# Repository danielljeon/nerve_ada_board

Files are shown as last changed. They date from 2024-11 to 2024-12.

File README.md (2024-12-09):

# nerve_ada_board



Nerve dev board using off-the-shelf modules.

> **Note: This design is now no longer under active development. The final
changes to the main branch are published as release tagged `v0.1.0-beta`,
see the release notes: [1.1 v0.1.0-beta](#11-v010-beta).**

> 💡**Hint:** To clone this repository use:
> ```shell
> git clone --recursive
> ```

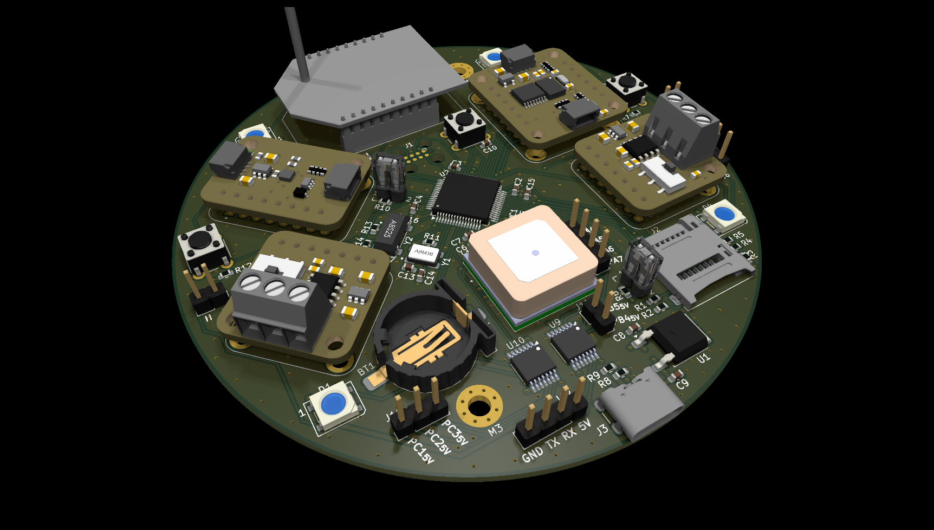
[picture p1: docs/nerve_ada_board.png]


---

<details markdown="1">
  <summary>Table of Contents</summary>

<!-- TOC -->
* [nerve_ada_board](#nerve_ada_board)
  * [1 Release Notes](#1-release-notes)
    * [1.1 v0.1.0-beta](#11-v010-beta)
      * [1.1.1 LSE Crystal](#111-lse-crystal)
      * [1.1.2 External Clock Crystal Tuning](#112-external-clock-crystal-tuning)
      * [1.1.3 GPS](#113-gps)
  * [2 Overview](#2-overview)
    * [2.1 Function Connectors](#21-function-connectors)
    * [2.2 Switches & Jumpers](#22-switches--jumpers)
    * [2.3 Plug-in Modules](#23-plug-in-modules)
    * [2.4 Breakout Connectors](#24-breakout-connectors)
  * [3 Development](#3-development)
    * [3.1 Worflow](#31-worflow)
    * [3.2 Submodules](#32-submodules)
  * [4 Production History](#4-production-history)
    * [4.1 v0.1.0-alpha-7b18788](#41-v010-alpha-7b18788)
<!-- TOC -->

</details>

---

## 1 Release Notes

### 1.1 v0.1.0-beta

Following the initial validation of components and software on this PCB design,
development has shifted to a more production-oriented
board: [nerve_pcb](https://github.com/danielljeon/nerve_pcb). While the base
components remain similar, many have been modified, with further
changes expected.

During the development of the new design, several hardware and PCB issues were
identified. Although this `README.md` will no longer be updated, the following
sections document the known issues as of the final release.

#### 1.1.1 LSE Crystal

The current LSE crystal on the STM32F446RE is the ABS25-32.768KHZ-6-T.

This is not the intended component; the correct crystal should have been the
`ABS25-32.768KHZ-T`, which has a more appropriate load capacitance specification
of 12.5 pF. The `ABS25-32.768KHZ-6-T` variant, with a 6 pF load capacitance, was
used inadvertently.

#### 1.1.2 External Clock Crystal Tuning

The crystal circuits use calculated capacitors that have not yet been fully
verified or fine-tuned. Specifically, the 32.768 kHz LSE crystal is likely using
incorrect capacitors with a value of 1.5 pF.

#### 1.1.3 GPS

The GPS module (`SAM-M10Q`) had not been verified to be functional as of the
release. However, this is likely due to software limitations rather than issues
with the hardware or PCB design.

---

## 2 Overview

Development board for the STM32
based [nerve](https://github.com/danielljeon/nerve) controller firmware.

### 2.1 Function Connectors

These connectors are fixed by hardware (PCB traces or the connector itself).

| Connector | Ref | Description |
|---|:---:|---|
| Tag-Connect TC2050 | J1  | Programming/debug connector |
| Hinge microSD Card | J2  | Portable storage, see [Molex product video](https://youtu.be/YY2V8z6UK7M?t=95) |
| USB-C 5 V Power | J3  | Power only USB-C, primary 5 V source |
| CR1220 Battery | BT1 | MCU and GPS battery source 3.3 V supply |
| CAN1 (Transceiver U7) | J7  | Pin 1: CAN1 High, Pin 2: CAN1 Low |
| CAN2 (Transceiver U8) | J8  | Pin 1: CAN2 High, Pin 2: CAN2 Low |

### 2.2 Switches & Jumpers

User controllable hardware and/or firmware driven inputs.

| Switch/Jumper | Ref | Description |
|---|:---:|---|
| MCU NRESET Switch | SW1 | Generic 6 mm TH button, push to reset |
| MCU PA0 Switch | SW2 | Generic 6 mm TH button, designed for SYS_WKUP0 |
| MCU PC13 Switch | SW3 | Generic 6 mm TH button, designed for SYS_WKUP1 |
| SDIO Card Detect Jumper | J4  | Close for card inserted (pull-down on close) |
| BOOT0 Jumper | J5  | Open for run flash memory (pull-down on open)  |

### 2.3 Plug-in Modules

Off-the-shelf plug-in boards, primarily from Adafruit.

| Manufacturer Part Number |  Ref | Manufacturer | Hardware Interface | Quantity | Description |
|---|:---:|---|---|---:|---|
| 4816 | U3 | Adafruit Industries LLC | 2.54 mm pitch TH | 1 | BMP390 Module |
| Digi XBee-PRO 900HP | U5 | Digi | 2 mm pitch TH | 1 | Long Range 900 MHz OEM RF Module |
| 4754 | U6 | Adafruit Industries LLC | 2.54 mm pitch TH | 1 | BNO085 Module |
| 5708 | U7, U8 | Adafruit Industries LLC | 2.54 mm pitch TH | 2 | TJA1051T/3 Module |

### 2.4 Breakout Connectors

Simple breakout connectors, driven fully or partially by firmware. See schematic
and firmware docs for details.

| Connector | Ref | Logic | Description |
|---|:---:|:-----:|---|
| WS2812B Extender | J6  |  5 V  | Pin 1: PWM, Pin 2: Ground, use separate supply (preventing over current draw) and common ground |
| SPI Breakout | J9  | 3.3 V | Pin 1: CS, Pin 2: SCK, Pin 3: MISO, Pin 4: MOSI |
| GPIO Breakout | J10 |  5 V  | Pin 1, 2, 3: GPIO 1, 2, 3 |
| PWM Breakout | J11 |  5 V  | Pin 1, 2: PWM 1, 2 |
| UART Camera | J12 |  5 V  | Pin 1: 5 V, Pin 2: UART RX, Pin 3: UART TX, Pin 4: Ground, design for low current camera |

---

## 3 Development

### 3.1 Worflow

Developed using KiCad with KiBot GitHub Actions
workflow, [kibot.yaml](.github/workflows/kibot.yaml).

- KiBot configurations found in [config.kibot.yaml](config.kibot.yaml).

CI/CD objectives:

1. ERC (Electrical Rule Check).
2. DRC (Design Rule Check).
3. PCB docs.
    - PCB layer docs (`.pdf` and `.svg`).
4. PCB manufacturing.
    - Gerber files (`.grb`).
    - Drill file (`.drl` and `.pdf` reference docs).
5. Assembly (fabrication service & hand assembly).
    - Pick-and-place assembly position file (`.pos`).
    - Component distributor ordering BoM (`.csv`).
    - General BoMs (`.xlsx` and `.html`).
    - Component placement guide (`.html`).
6. CAD.
    - (`.step`).

### 3.2 Submodules

This repository includes the submodule `component_library`, located
at: [component_library](https://github.com/danielljeon/component_library).

When cloning the repository, make sure to use the recursive option:

```shell
git clone --recursive
```

To update the submodule to its latest version in a cloned repository, use the
following command:

> Note: This is not recommended for this deprecated repository, as pulling
> updates from the submodule's latest commit may result in incompatibilities.

```shell
git submodule update --remote --merge
```

---

## 4 Production History

### 4.1 v0.1.0-alpha-7b18788

Commit: [7b18788](https://github.com/danielljeon/nerve_ada_board/commit/7b187884c03f280627d8443d2d9cc163f4b6956e).

<details markdown="1">
  <summary>Manufacturing & Assembly Details</summary>

**Manufacturing Information:**

Production date: 2024-10-22.

- Manufacturer: JLCPCB.
- Order: PCB, stencil.
- PCB specs (non-default):
    - PCB quantity: 5.
    - Surface Finish: LeadFree HASL.
    - Impedance control stackup: `JLC041611-7628`.
        - Outer Copper Weight: 1 oz.
        - Inner Copper Weight: 1 oz.
- Stencil specs (non-default):
    - Stencil quantity: 1.
    - Custom size: 100 mm x 100 mm (matching PCB dimensions).

**Assembly Information:**

Assembly date: 2024-11-09 to 2024-11-13.

- Assembled PCB quantity: 2.
- Process:
    - Stencil solder paste print by hand & soldering iron.
        - Solder paste: Chip Quik TS391LT `Bi57.6Sn42Ag0.4`.
    - SMD pick-and-place by hand.
    - Reflow with oven.
        - Roughly correct temperatures to solder paste docs.
        - Approximately doubled soak time due to oven limitations.

1. PCB 1 Notes:
    - Components: All placed except for GPS.
    - Damage to though holes for connector J4 mostly on bottom side.
        - First assembly was unsatisfactory.
        - Attempt to remove solder to reassemble header pins resulted in damage
          from aggressive force with the soldering iron.
        - Final result was functional, but the board damage remains on bottom
          side.
            - Suggested correction: heat soak the board, note also left in board
              evaluation section of this writeup.
        - Continuity tests showed no issues after completion.
    - Bridged pins on the U2 (STM32F446RE).
        - Likely too much solder paste and less than ideal definition of the
          printed solder paste.
        - Resolved with flux and reheat with soldering iron as well as use of
          solder wick.
            - Suggested correction: Cleaner swipe of the stencil with less
              solder paste.
2. PCB 2 Notes:
    - Components: All placed.
    - Misplacement of U2 (STM32F446RE).
        - Component shifted seemingly during reflow, some sides of the MCU had
          short or unconnected pins.
        - There was likely too much solder as well as potential misalignment
          during the pick-and-place by hand.
        - Attempts were made to reposition the component.
        - Some solder mask was removed near the pads, however no significant
          functional concerns were visible.
        - In order to limit potential damage to the board or components (
          particularly the expensive GPS module), the component was removed.
        - No pad damage was visible.
        - A replacement component was hand soldered with a soldering iron.
            - Suggested correction: Improve solder paste printing (again) and
              better hand placement. If too much paste was visible retry before
              any reflow. Perhaps, even holding the component in position with
              thin strips of kapton tape.
    - Bridged pins on the U9, U10 (TXB0104QPWRQ1).
        - Same details as U2 on PCB 1 (see above).
    - U4 GPS module solder joints are not visible (pads under component), but a
      continuity test of nets in every combination pair showed no shorts.

</details>

**Board Evaluation:**

- Large planes, especially ground. It is difficult to adjust through hole
  components that have ground pin(s).
    - Requires heat soaked board or potentially risky soldering iron
      temperatures.
- Some components such as resistors or capacitors are very close to through hole
  header pin connectors/jumpers.
    - Not super difficult to deal with, but something to keep in mind.
- The XBee Pro 900HP can cause clearance issues when trying to press-release the
  nearby TC2050-IDC's plastic clips.
- The Molex 472192001 hinge microSD card slot is functional, but slightly
  blocked by the Adafruit TJA1051T/3 breakout board.
    - This Would be easily resolved by implementing CAN circuit/components
      directly onto the PCB.

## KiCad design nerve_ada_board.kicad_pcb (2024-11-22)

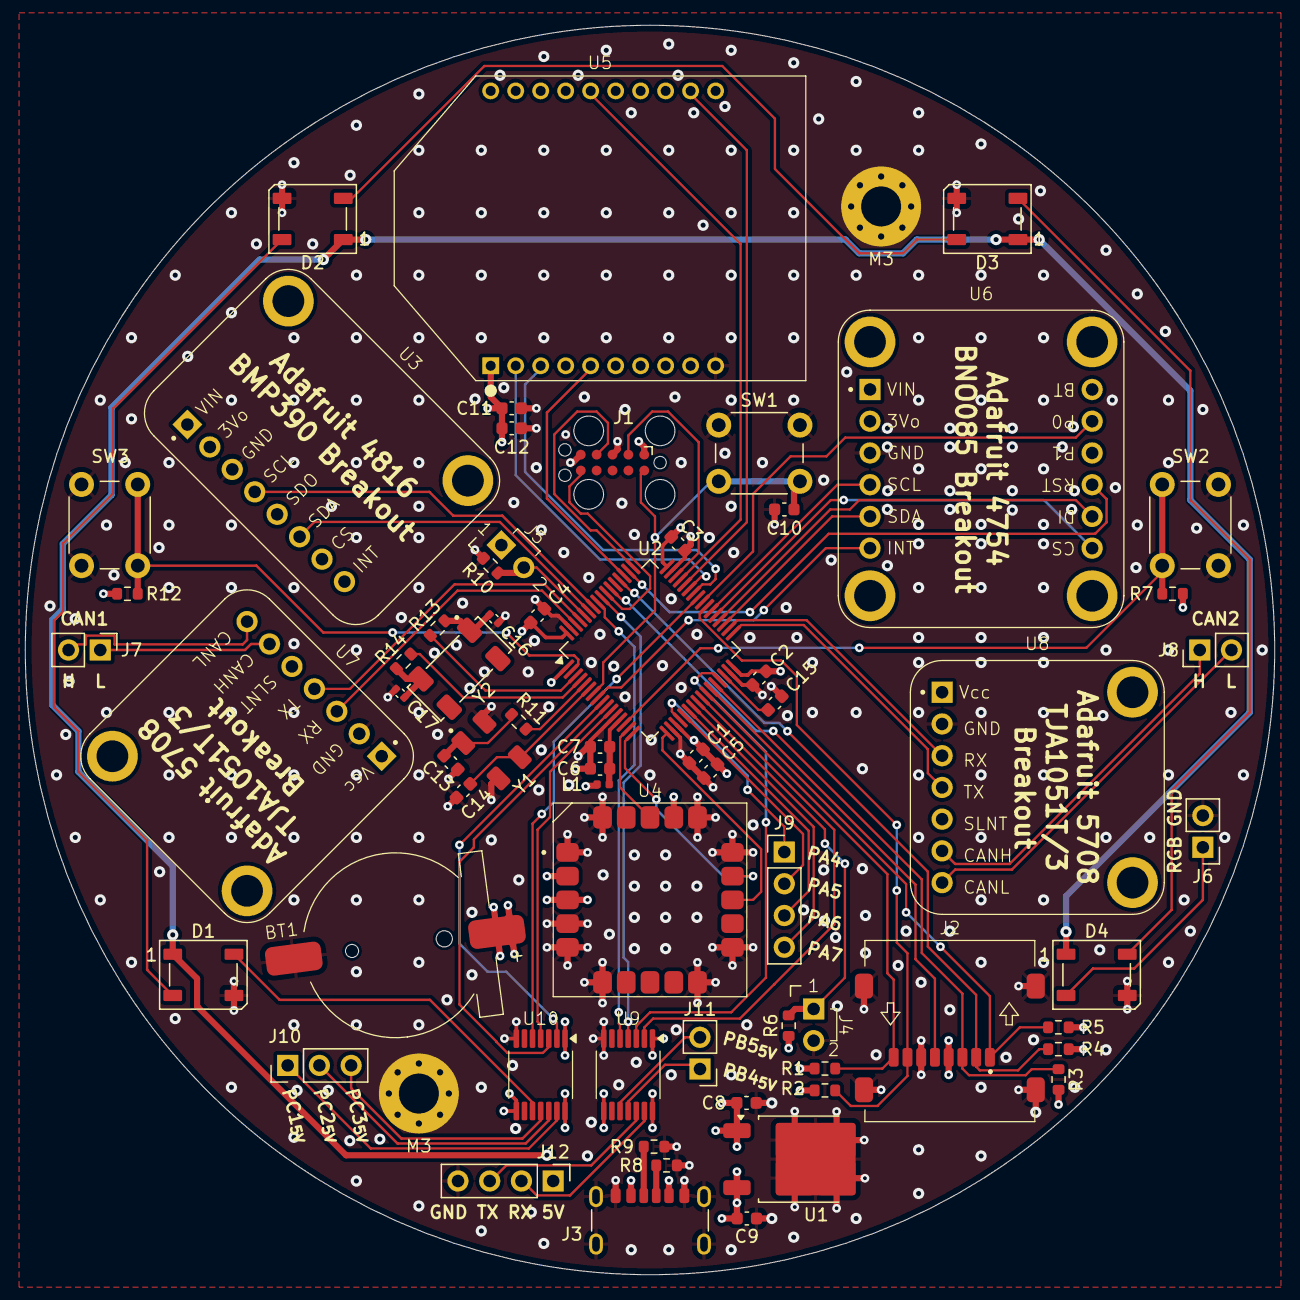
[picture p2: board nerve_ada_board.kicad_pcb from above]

Board: 4 copper layers, 100.0 x 100.0 mm, 66 parts (0 on the bottom side), 78 nets.

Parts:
BT1: CR1220; harwin_s8411-45r_cr1220_battery
C1, C2, C3, C4, C10: 100n; C_0603_1608Metric
C5: 4u7; C_0603_1608Metric
C6, C8, C12: 1u; C_0603_1608Metric
C7: 10n; C_0603_1608Metric
C9, C15: 2u2; C_0603_1608Metric
C11: 47p; C_0603_1608Metric
C13, C14: 20p; C_0603_1608Metric
C16, C17: 1p5; C_0402_1005Metric
D1, D2, D3, D4: WS2812B; LED_WS2812B_PLCC4_5.0x5.0mm_P3.2mm
H1, H2: M3; MountingHole_3.2mm_M3_Pad_Via
J1: TC2050-IDC; tag_connect_tc2050-idc
J2: 472192001; molex_472192001_microsd_hinge
J3: 2171750001; molex_2171750001_usb_c_6p
J4, J5: harwin_2p_2-54_jumper_open
J6: WS2812B; PinHeader_1x02_P2.54mm_Vertical
J7: CAN1; PinHeader_1x02_P2.54mm_Vertical
J8: CAN2; PinHeader_1x02_P2.54mm_Vertical
J9: PA4-7; PinHeader_1x04_P2.54mm_Vertical
J10: PC1-3; PinHeader_1x03_P2.54mm_Vertical
J11: PB4-5; PinHeader_1x02_P2.54mm_Vertical
J12: Camera; PinHeader_1x04_P2.54mm_Vertical
L1: 39n; L_0402_1005Metric
R1, R2, R3, R4, R5: 47k; R_0603_1608Metric
R6, R7, R10, R12: 10k; R_0603_1608Metric
R8, R9: 5k1; R_0603_1608Metric
R11, R13, R14: 0R; R_0603_1608Metric
SW1, SW2, SW3: SPST; SW_PUSH_6mm
U1: ld39150dt33-r; to-252-2_dpak-2-leg
U2: STM32F446RET; LQFP-64_10x10mm_P0.5mm
U3: adafruit_4816_bmp390
U4: SAM-M10Q; ublox_sam
U5: XBP9B-DMWT-002; xbee_pro_900hp
U6: adafruit_4754_bno085
U7, U8: adafruit_5708_tja1051t-3
U9, U10: TXB0104QPWRQ1; txb0104qpwrq1
Y1: 8M; xtal_abm3b-8.000mhz-10-1-u-t
Y2: 32k768; xtal_abs25-32.768khz-6-t

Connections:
+3.3VA: C6.1, C7.1, L1.2, U2.13 (VDDA)
+3.3VBATT: BT1.2, U2.1 (VBAT), U4.3 (V_BCKP)
+3V3: C1.1, C2.1, C3.1, C4.1, C5.1, C9.1, C11.1, C12.1, J1.1 (VCC), J2.4 (VDD), J5.1, L1.1, R1.1, R2.1, R3.1, R4.1, R5.1, R6.1, R7.1, R12.1, U1.3 (VO), U2.19 (VDD), U2.32 (VDD), U2.48 (VDD), U2.64 (VDD), U3.1 (VIN), U4.2 (V_IO), U4.17 (VCC), U5.1 (VCC), U5.14 (VREF), U6.1 (VIN), U6.10 (P1), U7.1 (Vcc), U8.1 (Vcc), U9.1 (V_{CCA}), U9.8 (OE), U10.1 (V_{CCA}), U10.8 (OE)
+5V: C8.1, D1.1 (VDD), D2.1 (VDD), D3.1 (VDD), D4.1 (VDD), J3.A9 (VBUS), J3.B9 (VBUS), J12.1, U1.1 (VI), U9.14 (V_{CCB}), U10.14 (V_{CCB})
/BOOT0: J5.2, R10.2, U2.60 (BOOT0)
/CAMERA_RX: J12.2, U9.13 (B1)
/CAMERA_TX: J12.3, U9.12 (B2)
/CAN1+: J7.1, U7.6 (CANH)
/CAN1-: J7.2, U7.7 (CANL)
/CAN1_RX: U2.61 (PB8), U7.4 (TX)
/CAN1_TX: U2.62 (PB9), U7.3 (RX)
/CAN2+: J8.1, U8.6 (CANH)
/CAN2-: J8.2, U8.7 (CANL)
/CAN2_RX: U2.33 (PB12), U8.4 (TX)
/CAN2_TX: U2.34 (PB13), U8.3 (RX)
/EXTI0_IMU_INT: U2.8 (PC0), U6.6 (INT)
/GPIO_GPS_RST: U2.15 (PA1), U4.18 (RESET_N)
/GPIO_IMU_P0: U2.40 (PC9), U6.11 (P0)
/GPIO_IMU_RST: U2.50 (PA15), U6.9 (RST)
/GPIO_RADIO_RST: U2.51 (PC10), U5.5 (~RESET)
/GPIO_SPI2_CS: U2.37 (PC6), U6.7 (CS)
/HSE_IN: R11.1, U2.5 (PH0_OSC_HSE_IN)
/HSE_OUT: C14.1, U2.6 (PH1_OSC_HSE_OUT), Y1.3
/I2C1_SCL: U2.58 (PB6), U3.4 (SCL)
/I2C1_SDA: U2.59 (PB7), U3.6 (SDA)
/LSE_IN: R13.1, U2.3 (PC14_OSC32_LSE_IN)
/LSE_OUT: R14.1, U2.4 (PC15_OSC32_LSE_OUT)
/NRST: C10.2, J1.10 (~RESET), SW1.2, U2.7 (NRST)
/PA4: J9.1, U2.20 (PA4)
/PA5: J9.2, U2.21 (PA5)
/PA6: J9.3, U2.22 (PA6)
/PA7: J9.4, U2.23 (PA7)
/PB4: U2.56 (PB4), U9.4 (A3)
/PB4_EXP: J11.1, U9.11 (B3)
/PB5: U2.57 (PB5), U9.5 (A4)
/PB5_EXP: J11.2, U9.10 (B4)
/PC1: U2.9 (PC1), U10.2 (A1)
/PC1_EXP: J10.1, U10.13 (B1)
/PC2: U2.10 (PC2), U10.3 (A2)
/PC2_EXP: J10.2, U10.12 (B2)
/PC3: U2.11 (PC3), U10.4 (A3)
/PC3_EXP: J10.3, U10.11 (B3)
/RGB_LED: D1.4 (DIN), U10.10 (B4)
/SDIO_CLK: J2.5 (CLK), U2.28 (PB2)
/SDIO_CMD: J2.3 (CMD), R3.2, U2.54 (PD2)
/SDIO_D0: J2.7 (DAT0), R2.2, U2.39 (PC8)
/SDIO_D1: J2.8 (DAT1), R1.2, U2.26 (PB0)
/SDIO_D2: J2.1 (DAT2), R5.2, U2.27 (PB1)
/SDIO_D3: J2.2 (DAT3/CD), R4.2, U2.52 (PC11)
/SDIO_DET: J4.1, R6.2, U2.24 (PC4)
/SPI2_MISO: U2.35 (PB14), U6.5 (SDA)
/SPI2_MOSI: U2.36 (PB15), U6.8 (DI)
/SPI2_SCK: U2.38 (PC7), U6.4 (SCL)
/SWCLK: J1.4 (SWCLK/TCK), U2.49 (PA14)
/SWDIO: J1.2 (SWDIO/TMS), U2.46 (PA13)
/SWO: J1.6 (SWO/TDO), U2.55 (PB3)
/TIM1_CH1_PWM: U2.41 (PA8), U10.5 (A4)
/USART1_CTS: U2.44 (PA11), U5.12 (~CTS/DIO7)
/USART1_RTS: U2.45 (PA12), U5.16 (~RTS/DIO6)
/USART1_RX: U2.43 (PA10), U5.2 (DOUT/DIO13)
/USART1_TX: U2.42 (PA9), U5.3 (DIN/~CONFIG/DIO14)
/USART2_RX: U2.17 (PA3), U4.13 (TXD)
/USART2_TX: U2.16 (PA2), U4.14 (RXD)
/USART3_RX: U2.25 (PC5), U9.2 (A1)
/USART3_TX: U2.29 (PB10), U9.3 (A2)
GND: BT1.1, C1.2, C2.2, C3.2, C4.2, C5.2, C6.2, C7.2, C8.2, C9.2, C10.1, C11.2, C12.2, C13.2, C14.2, C15.2, C16.2, C17.2, D1.3 (VSS), D2.3 (VSS), D3.3 (VSS), D4.3 (VSS), H1.1, H2.1, J1.3 (GND), J1.5 (GND/VPROG), J2.6 (VSS), J2.G1 (GND), J2.G2 (GND), J2.G3 (GND), J2.G4 (GND), J3.A12 (GND), J3.B12 (GND), J3.S1 (SHIELD), J4.2, J6.2, J12.4, R8.2, R9.2, R10.1, SW1.1, SW2.2, SW3.1, U1.2 (GND), U2.12 (VSSA), U2.18 (VSS), U2.31 (VSS), U2.47 (VSS), U2.63 (VSS), U3.3 (GND), U4.1 (GND), U4.4 (GND), U4.5 (GND), U4.6 (GND), U4.10 (GND), U4.11 (GND), U4.15 (GND), U4.16 (GND), U4.20 (GND), U5.10 (GND), U6.3 (GND), U7.2 (GND), U8.2 (GND), U9.7 (GND), U10.7 (GND), Y1.2, Y1.4
unnamed: C13.1, R11.2, Y1.1
unnamed: C16.1, R13.2, Y2.1
unnamed: C17.1, R14.2, Y2.2
unnamed: D1.2 (DOUT), D2.4 (DIN)
unnamed: D2.2 (DOUT), D3.4 (DIN)
unnamed: D3.2 (DOUT), D4.4 (DIN)
unnamed: D4.2 (DOUT), J6.1
unnamed: J3.A5 (CC1), R9.1
unnamed: J3.B5 (CC2), R8.1
unnamed: R7.2, SW2.1, U2.14 (PA0)
unnamed: R12.2, SW3.2, U2.2 (PC13)
unnamed: C15.1, U2.30 (VCAP_1)

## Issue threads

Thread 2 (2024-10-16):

Custom footprint DRC mismatch warning

danielljeon, 2024-10-16:
Custom footprint `harwin_s8411-45r_cr1220_coin_battery_cell` causes DRC `lib_footprint_mismatch` warning.

Snippet of **KiBot DRC** workflow job log:

```
Exporting KIBOT_3D_MODELS=/github/home/cache_3d
Options: -c 'config.kibot.yaml' -d 'Generated' -s erc -i
Using SCH file: nerve_ada_board.kicad_sch
- Running the DRC
WARNING:(W145) 1 DRC warnings detected (kibot.pre_drc - pre_drc.py:146)
WARNING:(W145) (lib_footprint_mismatch) Footprint 'harwin_s8411-45r_cr1220_coin_battery_cell' does not match copy in library 'common'.
    @(105.5 mm, 128.3 mm): Footprint BT1
    Check: Violations (kibot.pre_drc - pre_drc.py:146)
Found 2 unique warning/s (5 total, 3 filtered)
```

The footprint is maintained as part of the [component_library](https://github.com/danielljeon/component_library) submodule.

Original warning raise was observed by KiBot workflows in during #1 pull request.
- This was the first time the KiBot workflow was triggered in this repo for ERC/DRC (only runs on main branch targets).
- At the time local KiCad DRC would pass with no warnings, yet KiBot failed after multiple tries of ensuring matching footprints.
- After #1 was rebased successfully into main, local KiCad raised the same warning in DRC one time.
  - Since then DRC passes with no warnings.

danielljeon, 2024-10-17:
Resolved by b9a14b5.

The DRC now passes with zero warnings. The solution involved fully simplifying the silkscreen and fabrication geometry on the footprint. It’s possible the issue wasn’t due to complexity but rather something related to the original footprint, which was derived from public resources.

Further research would be ideal, but the issue is being closed for now.

Closed 2024-10-17.

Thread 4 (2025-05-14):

Dev Board Firmware Validation

danielljeon, 2025-05-14:
Issue to track dev board firmware validation using `nerve_ada_board` on project trackers.

Closed 2025-05-14.

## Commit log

2024-09-05 Add gitignore for KiCad
2024-10-16 Add initial WIP design
    [nerve_ada_board.kicad_pcb, nerve_ada_board.kicad_sch]
2024-10-16 Add WIP basics, power and sensors
    [nerve_ada_board.kicad_sch]
2024-10-16 Add XBee radio and u-blox GPS
    [nerve_ada_board.kicad_sch]
2024-10-16 Add very early full schematic
    [nerve_ada_board.kicad_sch]
2024-10-16 Clean up schematic
    [nerve_ada_board.kicad_sch]
2024-10-16 Add WS2812B RGB LEDs
    [nerve_ada_board.kicad_sch]
2024-10-16 Remove battery jumpers and fix WS2812B power
    [nerve_ada_board.kicad_sch]
2024-10-16 Update and organize symbols on schematic
    [nerve_ada_board.kicad_sch]
2024-10-16 Add level shifter and buzzer, organize schematic
    [nerve_ada_board.kicad_sch]
2024-10-16 Update library, fix power circuits, clean up
    [nerve_ada_board.kicad_sch]
2024-10-16 Update symbols from library
    [nerve_ada_board.kicad_sch]
2024-10-16 Update jumper with library, clean up
    [nerve_ada_board.kicad_sch]
2024-10-16 Pass ERC, add final MCU breakouts, clean up
    [nerve_ada_board.kicad_sch]
2024-10-16 Clean up REF annotation sequence
    [nerve_ada_board.kicad_sch]
2024-10-16 Update library and LSE crystal on schematic
    [nerve_ada_board.kicad_sch]
2024-10-16 Switch to hierarchical labels and major clean up
    [nerve_ada_board.kicad_sch]
2024-10-16 Update library and fix annotations
    [nerve_ada_board.kicad_sch]
2024-10-16 Update power circuits and minor clean up
    [nerve_ada_board.kicad_sch]
2024-10-16 Update component library and schematic
    [nerve_ada_board.kicad_sch]
2024-10-16 Update component library and schematic HSE
    [nerve_ada_board.kicad_sch]
2024-10-16 Clean up annotations and remove bad net label
    [nerve_ada_board.kicad_sch]
2024-10-16 Update component_library and schematic
    [nerve_ada_board.kicad_sch]
2024-10-16 Add second level shifter and clean up
    [nerve_ada_board.kicad_sch]
2024-10-16 Improve expansion peripherals and remove buzzer
    [nerve_ada_board.kicad_sch]
2024-10-16 Add connector footprints
    [nerve_ada_board.kicad_sch]
2024-10-16 Change to jumper based BOOT0
    [nerve_ada_board.kicad_sch]
2024-10-16 Update annotations
    [nerve_ada_board.kicad_sch]
2024-10-16 Assign capacitor, resistor, inductor footprints
    [nerve_ada_board.kicad_sch]
2024-10-16 Fix bad net label
    [nerve_ada_board.kicad_sch]
2024-10-16 Add WIP PCB layout
    [nerve_ada_board.kicad_pcb]
2024-10-16 Update stackup and board setup for fab
    [nerve_ada_board.kicad_pcb]
2024-10-16 Add SWD, PWR and GND netclasses
2024-10-16 Update board setup and organize basic netclasses
    [nerve_ada_board.kicad_pcb]
2024-10-16 Add ground planes
    [nerve_ada_board.kicad_pcb]
2024-10-16 Add CAN net labels for PCB diff pair
    [nerve_ada_board.kicad_sch]
2024-10-16 Add WIP PCB, pass DRC
    [nerve_ada_board.kicad_pcb]
2024-10-16 Remove breakout GPIO PC12
    [nerve_ada_board.kicad_sch]
2024-10-16 Clean up power plane, repass DRC, minor fixes
    [nerve_ada_board.kicad_pcb]
2024-10-16 Add symbol and footprint library tables
2024-10-16 Attempt fix Kibot lib_footprint_mismatch
    [nerve_ada_board.kicad_pcb]
2024-10-16 Attempt 2, Kibot lib_footprint_mismatch
    [nerve_ada_board.kicad_pcb]
2024-10-16 Attempt 3, Kibot lib_footprint_mismatch
    [nerve_ada_board.kicad_pcb]
2024-10-16 Attempt 4, Kibot lib_footprint_mismatch
    [nerve_ada_board.kicad_pcb]
2024-10-16 Update config.kibot.yaml, finalize BoM fields
2024-10-16 Plane 1 ground pour and pass DRC
    [nerve_ada_board.kicad_pcb]
2024-10-16 Update component library and footprints on PCB
    [nerve_ada_board.kicad_pcb]
2024-10-16 Attempt 5, Kibot lib_footprint_mismatch
    [nerve_ada_board.kicad_pcb]
2024-10-16 Update CR1220 battery holder component
    [nerve_ada_board.kicad_pcb, nerve_ada_board.kicad_sch]
2024-10-17 Update CR1220 component, again
    [nerve_ada_board.kicad_pcb, nerve_ada_board.kicad_sch]
2024-10-17 Update CR1220 component, again 3
    [nerve_ada_board.kicad_pcb]
2024-10-17 Resolve ERC duplicate labelling warning
    [nerve_ada_board.kicad_pcb, nerve_ada_board.kicad_sch]
2024-10-19 Flight ready alpha and update components
    [nerve_ada_board.kicad_pcb, nerve_ada_board.kicad_sch]
2024-10-19 Fix SDIO card detect for active low
    [nerve_ada_board.kicad_pcb, nerve_ada_board.kicad_sch]
2024-10-19 Swap to LD39150DT33-R regulator
    [nerve_ada_board.kicad_pcb, nerve_ada_board.kicad_sch]
2024-10-20 Clean up layout around SDIO
    [nerve_ada_board.kicad_pcb]
2024-10-20 Move LEDs to 4 corners, cleanup layout
    [nerve_ada_board.kicad_pcb]
2024-10-20 Add mounting holes and cleanup layout
    [nerve_ada_board.kicad_pcb, nerve_ada_board.kicad_sch]
2024-10-21 Update component_library and PCB
    [nerve_ada_board.kicad_pcb]
2024-10-21 Add GND plane stitching and cleanup layout
    [nerve_ada_board.kicad_pcb]
2024-10-21 Final cleanup, fix stackup, adjust page docs
    [nerve_ada_board.kicad_pcb, nerve_ada_board.kicad_sch]
2024-10-23 Attempt fix KiBot CSV BOM
2024-10-23 Attempt fix KiBot CSV BOM 2
2024-10-23 Attempt fix KiBot CSV BOM 3
2024-10-23 Adjust KiBot CSV BOM for part quotes
2024-10-25 Add README.md docs and add board picture
2024-10-30 Clean up silkscreen, fill mounting hole reliefs
    [nerve_ada_board.kicad_pcb]
2024-10-30 Update J6 WS2812B connector pin order
    [nerve_ada_board.kicad_pcb, nerve_ada_board.kicad_sch]
2024-11-09 Add board assembly and evaluation docs
2024-11-12 Update component library and docs picture
    [nerve_ada_board.kicad_pcb]
2024-11-12 Attempt fix WS2812B footprint mismatch warning
    [nerve_ada_board.kicad_pcb]
2024-11-12 Attempt fix WS2812B footprint mismatch warning 2
    [nerve_ada_board.kicad_pcb]
2024-11-12 Attempt fix WS2812B footprint mismatch warning 3
    [nerve_ada_board.kicad_pcb]
2024-11-21 Update component_library and propagate changes
    [nerve_ada_board.kicad_pcb]
2024-11-21 Update PCB docs picture
2024-11-22 Remove thermal reliefs on mounting holes
    [nerve_ada_board.kicad_pcb]
2024-11-22 Fix breakout header silkscreen labels
    [nerve_ada_board.kicad_pcb]
